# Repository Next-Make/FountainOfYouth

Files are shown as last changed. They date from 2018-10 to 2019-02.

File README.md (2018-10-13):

# Fountain of Youth

## Members
* Miles Dai
* Shahul Alam
* Austin Wang
* Alex Cuellar
* Lydia Morales-Anderson
* Chelsea Ajunwa

## Project Updates
### October 13, 2018
The 4-ohm, 3-watt speaker arrived in the mail along with the Neopixels and the MAX98357A 3W amplifier.

The amplifier takes in I2S commands. The Arduino Uno does not actually contain a I2S interface, so the project has been moved to Miles's Teensy 3.2. The Teensy code in `speaker.ino` currently accepts audio signals through USB and generates I2S signals that are fed into the MAX98357A. The pinouts are as follows:

| Pin Name |Function | MAX98357A Pin | Teensy Pin |
|:-:|:-:|:-:|:-:|
| LRCLK | Left-right channel selector | LRC | 23 |
| BCLK | Bit Clock, 1.41 MHz | BCLK | 9 |
| TX | Digital Audio Data Input | DIN | 22 |
| Gain | Audio gain | Gain | - |
| Shutdown | Active low shutdown, also channel selector | SD | - |
| GND | Ground | GND | - |
| Vin | Speaker supply voltage | Vin | - |

**Note that the speaker driver should be driven from the bench power supply at 5V and not the USB port since it has the potential to draw over 400 mA.**

The signals are shown below and were generated with music playing through the USB port.

Bit Clock (probing pin 9 on the Teensy):

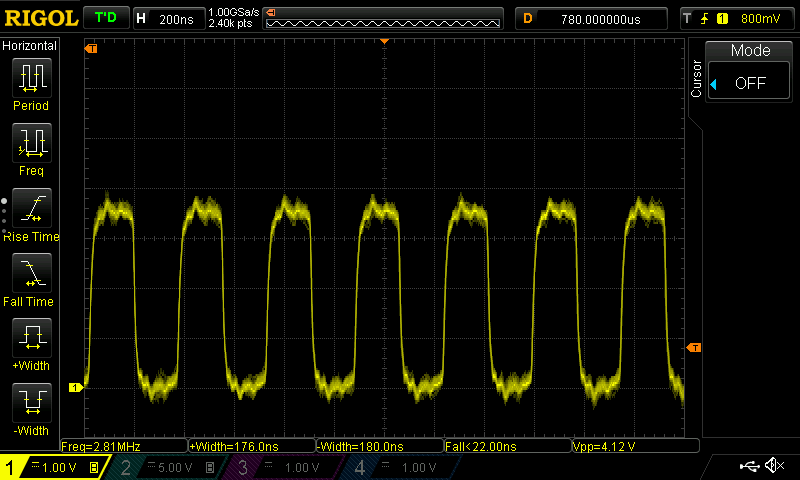
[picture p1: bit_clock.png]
Bit Clock


Audio Signal (probing pin 22 on the Teensy):

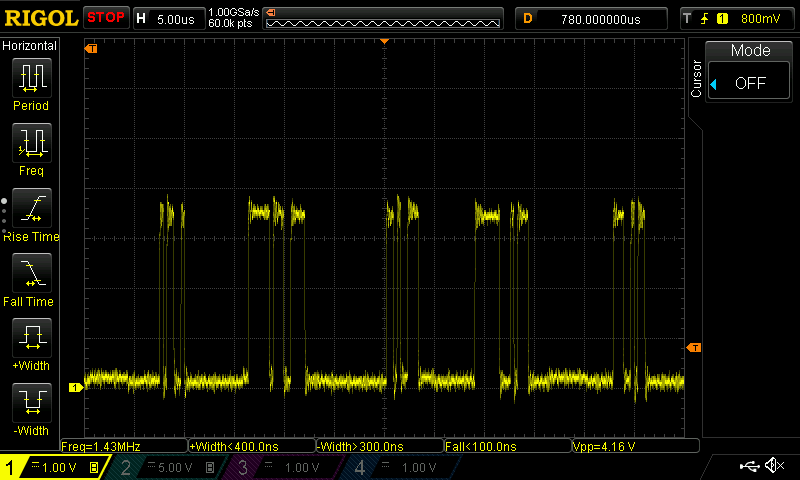
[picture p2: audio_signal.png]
Audio Signal


Audio Signal with Bit Clock Timing Synchronization:
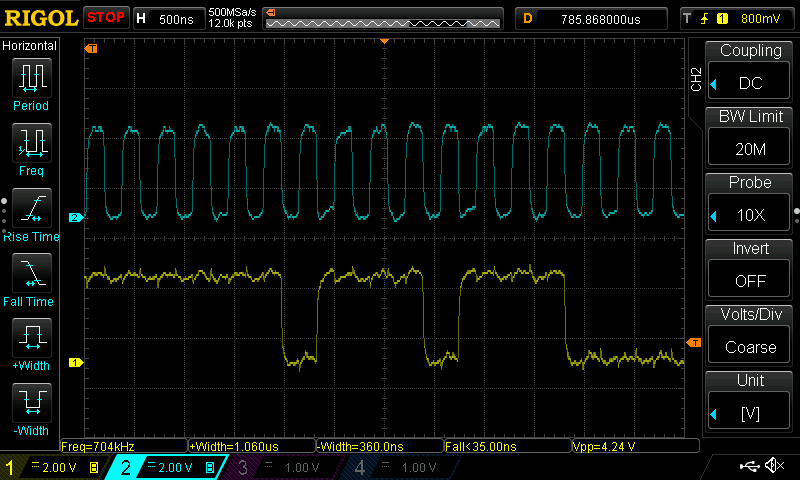
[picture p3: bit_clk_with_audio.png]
Bit clock with audio signal


The Teensy Audio library has a host of other useful functions found [here](https://www.pjrc.com/teensy/td_libs_Audio.html).

Currently, the 60 Hz sine wave can be generated using something like Audacity to produce the audio signal and then just play that over USB. When generating the signal, avoid using the full amplitude since that causes some noise artifacts in the speaker. 80% seems to work fairly well.

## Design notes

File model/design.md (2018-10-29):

# Hardware Model Design

The design consists of several major components:
- *Release mechanism* - the top of the fountain, which includes the speaker and release nozzle where water exits the internal structure
- *Visual chamber* - consists of the open space, lined with LEDs on the side wall
- *Vascular system* - the system including the collection bucket, pump, and tubes which transport water from the bottom back to the top of the fountain
- *Brain* - the system of electronics, stored at the bottom of the fountain

## Release Mechanism

The release mechanism is a closed, internal chamber containing primarily the speaker, which creates the oscillatory output of the output water stream, connected to the exit end of the tube. The opening to release water should be at the bottom of the top chamber.

## Visual chambers

The visual chamber consists of LEDs along each side and a visible stream of water down the center. The chamber will be sealed off with transparent plastic on the front and back to prevent tampering with the water stream.

The sides of the visual chambers should contain the tube carrying water up to the top as well as the wires for the speaker.

## Vascular system

The vascular system should include the collection bucket, which collects the water and feeds back into the transport tube. The peristaltic pump should be stored in the bottom chamber and will be used to pump water back to the top.

## Brain

The system of electronics which powers the entire system. The bottom panel of the electronics should be easily removable from the rest of the system for easy electrical debugging, and an interface should exist to allow for new program loading (i.e. the micro USB interface should be accessible while the entire system is contained within the bottom chamber). There should also be an easy interface to provide power to the system.

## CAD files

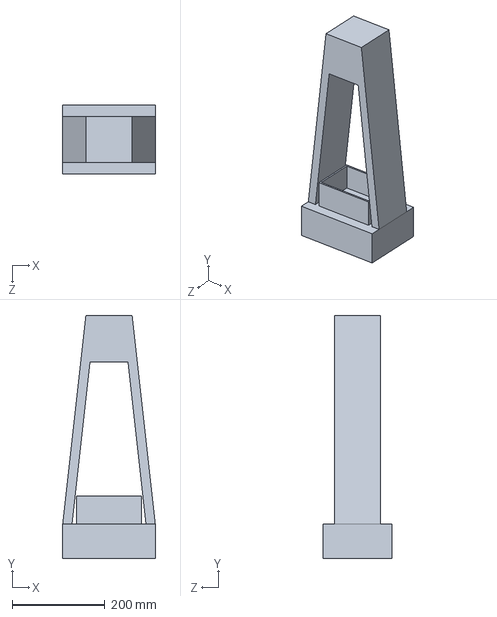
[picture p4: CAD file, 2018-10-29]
model/mockup_model.SLDPRT
200.0 x 525.0 x 150.0 mm

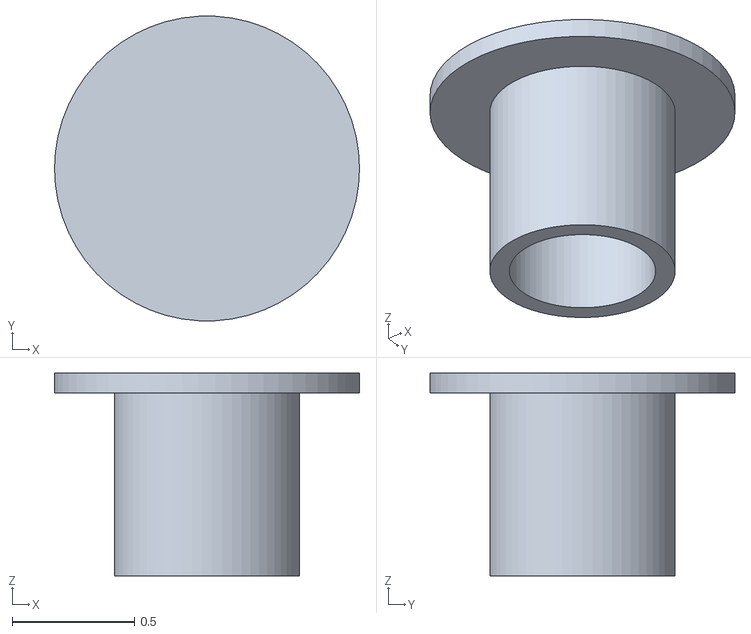
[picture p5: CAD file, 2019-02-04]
spool_inner.stl
1.25 x 1.25 x 0.83

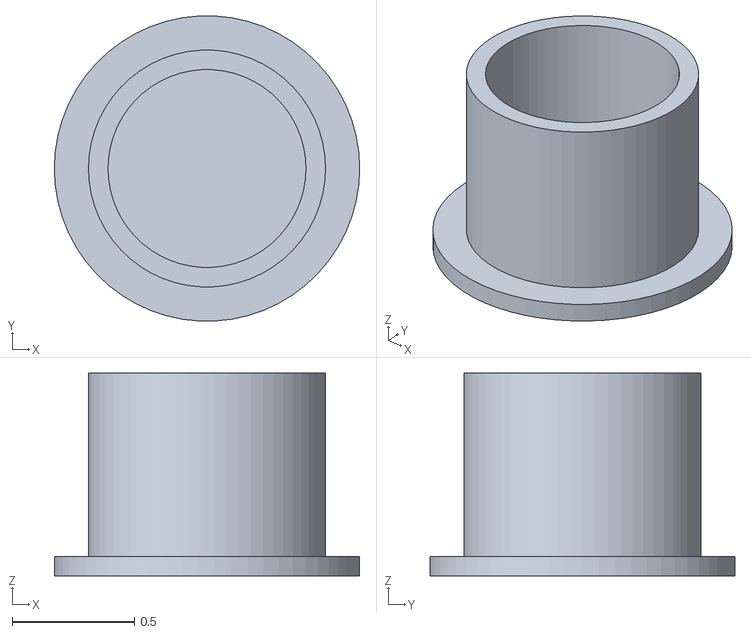
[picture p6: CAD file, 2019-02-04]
spool_outer.stl
1.25 x 1.25 x 0.83

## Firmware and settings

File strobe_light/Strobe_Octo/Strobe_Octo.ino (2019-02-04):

/*  
  Required Connections
  --------------------
    pin 2:  LED Strip #1    OctoWS2811 drives 8 LED Strips.
    pin 14: LED strip #2    All 8 are the same length.
    pin 7:  LED strip #3
    pin 8:  LED strip #4    A 100 ohm resistor should used
    pin 6:  LED strip #5    between each Teensy pin and the
    pin 20: LED strip #6    wire to the LED strip, to minimize
    pin 21: LED strip #7    high frequency ringining & noise.
    pin 5:  LED strip #8
    pin 15 & 16 - Connect together, but do not use
    pin 4 - Do not use
    pin 3 - Do not use as PWM.  Normal use is ok.

  This test is useful for checking if your LED strips work, and which
  color config (WS2811_RGB, WS2811_GRB, etc) they require.
*/

#include <OctoWS2811.h>
#include <SPI.h>
#include <SD.h>
#include <SerialFlash.h>

#define RED    0xAA0000
#define GREEN  0x00FF00
#define BLUE   0x0000FF
#define YELLOW 0xFFFF00
#define PINK   0xFF1088
#define ORANGE 0xE05800
//#define WHITE  0xFFFFFF
#define BLACK  0x000000

// Less intense...
//#define RED    0x160000
//#define GREEN  0x001600
//#define BLUE   0x000016
//#define YELLOW 0x101400
//#define PINK   0x120009
//#define ORANGE 0x100400
#define WHITE  0xFFFFFF

#define MAX_FREQ 65
#define MIN_FREQ 60
#define LEDS_PER_STRIP 60
#define LED_FREQ 60 // Hz

#define PUMP_PIN 9


/*
 * Global Variables
 */

DMAMEM int displayMemory[LEDS_PER_STRIP * 6];
int drawingMemory[LEDS_PER_STRIP * 6];

const int config = WS2811_GRB | WS2811_800kHz;

int ledPeriod;

OctoWS2811 leds(LEDS_PER_STRIP, displayMemory, drawingMemory, config);

elapsedMicros ledTimer;
elapsedMicros redTimer;
elapsedMicros blueTimer;
elapsedMillis pumpTimer;
bool ledOn;
int pumpFreq = 5;
int pumpPeriod;



/*
 * Helper Methods
 */

void turnLedsOn() {
  for(int i = 0; i < leds.numPixels(); i++) {
    leds.setPixel(i, WHITE);
  }
  leds.show();
}

//void turnLedsOnRed() {
//  for(int i = 0; i < leds.numPixels(); i++) {
//    leds.setPixel(i, RED);
//  }
//  leds.show();
//}
//
//void turnLedsOnBlue() {
//  for(int i = 0; i < leds.numPixels(); i++) {
//    leds.setPixel(i, BLUE);
//  }
//  leds.show();
//}
//
//void turnLedsOnGreen() {
//  for(int i = 0; i < leds.numPixels(); i++) {
//    leds.setPixel(i, GREEN);
//  }
//  leds.show();
//}

void turnLedsOnColor(int color) {
  for(int i = 0; i < leds.numPixels(); i++) {
    leds.setPixel(i, color);
  }
  leds.show();
}

void turnLedsOff() {
  for(int i = 0; i < leds.numPixels(); i++) {
    leds.setPixel(i, BLACK);
  }
  leds.show();
}
int ledColor;

void setup() {
  leds.begin();
  turnLedsOn();
  leds.show();
  pinMode(PUMP_PIN, OUTPUT);
  ledOn = true;
  ledPeriod = 1000000 / LED_FREQ; // period in microseconds because ledTimer is an elapsedMicros
  pumpPeriod = 1000 / pumpFreq;
  digitalWrite(PUMP_PIN, HIGH);
  ledColor = 0;
}


void loop() {
  int freq = analogRead(A4);
  freq = map(freq, 0, 1024, MIN_FREQ, MAX_FREQ);
  ledPeriod = 1000000 / freq;

  if(ledTimer < ledPeriod / 950) { // 0.1% duty cycle
    if(!ledOn){
      switch(ledColor) {
        case 0: 
          turnLedsOnColor(BLUE);
          ledColor += 1;
          break;
        case 1:
          turnLedsOnColor(GREEN);
          ledColor += 1;
          break;
        case 2:
          turnLedsOnColor(RED);
          ledColor = 0;
          break;
      }
      ledOn = true;  
    }
    
  } else if (ledTimer < ledPeriod) {
    if(ledOn) {
      turnLedsOff();
      ledOn = false;
    }
  } else {
    ledTimer = 0;
  }
  
  if(pumpTimer < pumpPeriod / (11/10)) { // 50% duty cycle
    digitalWrite(PUMP_PIN, HIGH);
  } else if (pumpTimer < pumpPeriod) {
    digitalWrite(PUMP_PIN, LOW);
  } else {
    pumpTimer = 0;
>>>>>>> 5f987616fe31b58dc8da3170bc33714f6eb1cc77
  }
}


void setup() {
  leds.begin();
  turnLedsOn();
  leds.show();
  pinMode(14, INPUT);
  pinMode(PUMP_PIN, OUTPUT);
  pumpOn = true;
  ledOn = true;
  ledPeriod = 1000 / LED_FREQ;
  pumpPeriod = 1000 / pumpFreq;
  digitalWrite(PUMP_PIN, HIGH);
}



void loop() {
  
//  float pot_val = analogRead(14);
//  FREQUENCY = map(pot_val, 0, 1024, MIN_FREQ, MAX_FREQ);
//  waveform1.frequency(FREQUENCY);
//  int DELAY_VAL = (int) (1/FREQUENCY * 1/2 * NUM_MICROSECONDS_PER_SECOND); // delay for half a second
//
//  Serial.println(DELAY_VAL);
//  delayMicroseconds(DELAY_VAL);
//  for (int i=0; i<leds.numPixels(); i++){
//     leds.setPixel(i, WHITE);
//  }
//  leds.show();  
//  delayMicroseconds(DELAY_VAL);
//  for (int i=0; i<leds.numPixels(); i++){
//     leds.setPixel(i, BLACK);
//  }
//  leds.show();

  if(ledTimer < ledPeriod / 2 && !ledOn) {
    turnLedsOn();
    ledOn = true;
  } else if (ledTimer < ledPeriod && ledOn) {
    turnLedsOff();
    ledOn = false;
  } else {
    ledTimer = 0;
  }
  digitalWrite(PUMP_PIN, HIGH);
  if(pumpTimer < pumpPeriod / 2 && !pumpOn) {
    digitalWrite(PUMP_PIN, HIGH);
    pumpOn = true;
  } else if (pumpTimer < pumpPeriod && pumpOn) {
    digitalWrite(PUMP_PIN, LOW);
    pumpOn = false;
  } else {
    pumpTimer = 0;
  }
}

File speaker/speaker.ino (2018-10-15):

#include <Audio.h>
#include <Wire.h>
#include <SPI.h>
#include <SD.h>
#include <SerialFlash.h>

AudioSynthWaveform       waveform1;      //xy=110,75
AudioOutputI2S           i2s1;           //xy=365,94
AudioConnection          patchCord1(waveform1, 0, i2s1, 0);
AudioConnection          patchCord2(waveform1, 0, i2s1, 1);
AudioControlSGTL5000     sgtl5000_1;     //xy=302,184

void setup() {
  AudioMemory(12);
//  AudioMemory(15);
  waveform1.begin(WAVEFORM_SINE);
  waveform1.frequency(440);
  waveform1.amplitude(0.3);
}

void loop() {
  for(int i = 220; i < 441; i++){
    waveform1.frequency(i);
    delay(50);
  }
  
  for(int i = 440; i > 219; i--){
    waveform1.frequency(i);
    delay(50);
  }
}

// Teensyduino 1.35 & earlier had a problem with USB audio on Macintosh
// computers.  For more info and a workaround:
// https://forum.pjrc.com/threads/34855-Distorted-audio-when-using-USB-input-on-Teensy-3-1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

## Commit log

2018-10-08 Added code to strobe LED light.
2018-10-13 Added code to pass signals from USB to I2S through the Teensy.
2018-10-13 Added documentation for Teensy audio setup
2018-10-15 Teensy now generates sine wave on board without usb connection.
2018-10-29 Started models folder with mock model
    [mockup_model.SLDPRT]
2019-02-04 added solenoid spools
    [spool_inner.stl, spool_outer.stl]
2019-02-04 Fixed-up numbers for stroboscopic effect.
    [Strobe_Octo.ino]
